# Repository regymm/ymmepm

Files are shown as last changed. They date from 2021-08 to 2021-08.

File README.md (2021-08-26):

## YMMEPM

#### CPLD Dev Board & Handheld Serial Terminal

Board with Altera MAX II EPM1270. With a pluggable 480x320 LCD screen and a matrix keyboard, it work well as a handheld serial terminal. [Video](https://t.me/petergulife/174). 

**Gallery**

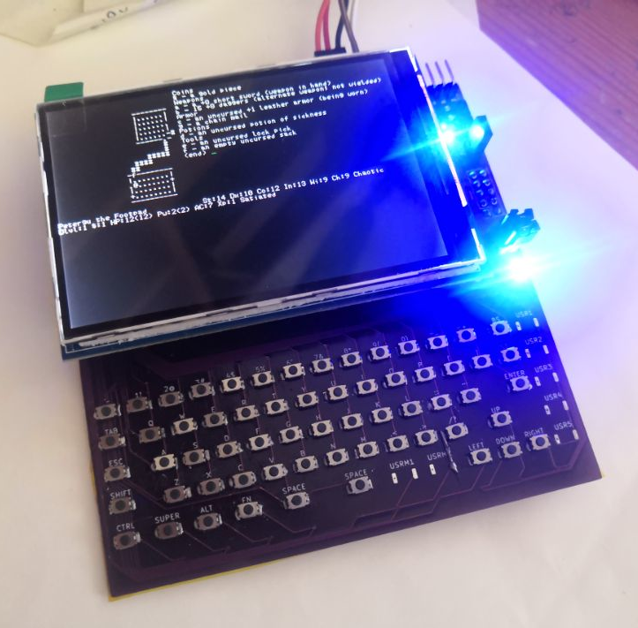
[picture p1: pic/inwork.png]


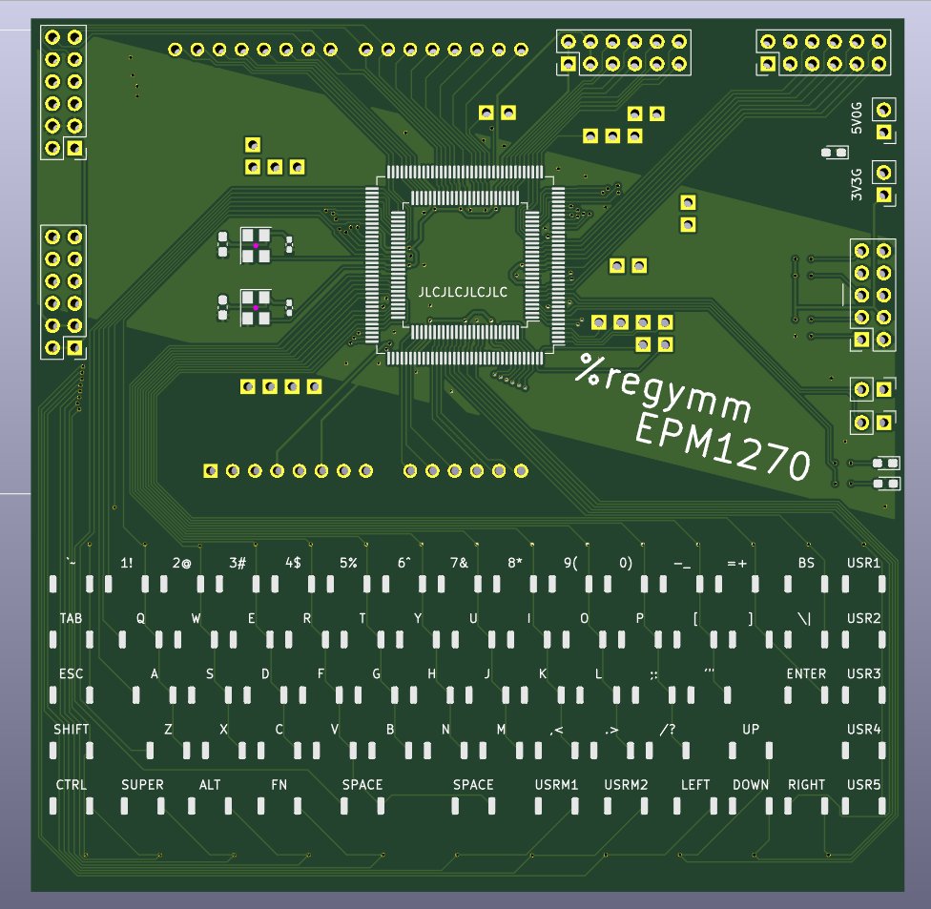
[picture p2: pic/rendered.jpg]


**The terminal**

`rtl/lcd_terminal.v`

Due to the scares resource of the EPM1270, the terminal supports only basic cursor movement and clear VT100(`^[[X`) sequences, others are detected and ignored. Have to put character pixel lists into slow UFM, so only up to 19200 baud rate. In case of Linux, bash and commands like `ls` work. `nano` won't display correctly and the editor that works is `ed` or my [ymedit](https://github.com/regymm/ymedit). CTS flow control is utilized to avoid losing chars when clearing full screen. (so need to connect 5 wires to use: 5V0, GND, rx, tx, cts)

**The keyboard**

`rtl/uart_keyboard.v`

Currently support only single-byte chars, arrow keys won't work. In code UP and RIGHT are used as extra SHIFT and CTRL. 

Covering keyboard with high-temperature yellow tape will significantly improve type feeling. 

**Design**

Simple is the main concern ... or not?

Single 3V3, or single 5V0 with ASM1117 to 3V3. 

Right two PMODs directly connected to CPLD. Left 2 PMODs share the Arduino pins(these literally give the plugged LCD screen a PMOD interface). Spare IOs scattered here and there. 

1 power LED, 2 user LEDs, 2 user jumpers. 2 oscillators. A strange matrix keyboard. 

For the simplest verification, only the CPLD, power pins, and JTAG pins are needed. Even caps on the back can be left empty. 

Footprint is compatible with EPM1270/570/240 TQFP144/100, but certainly the full terminal can only fit into EPM1270(~ 90% logic elements used). 

**Bugs**

5V is not connected to the Arduino pin. Fly a wire from ASM1117 if using 5V LCD screen. 

JTAG header pins should be soldered on back of the board. 

Still some tiny problems in the supported VT100 controls. But if the fix is paid in extra logic elements, I have to consider.

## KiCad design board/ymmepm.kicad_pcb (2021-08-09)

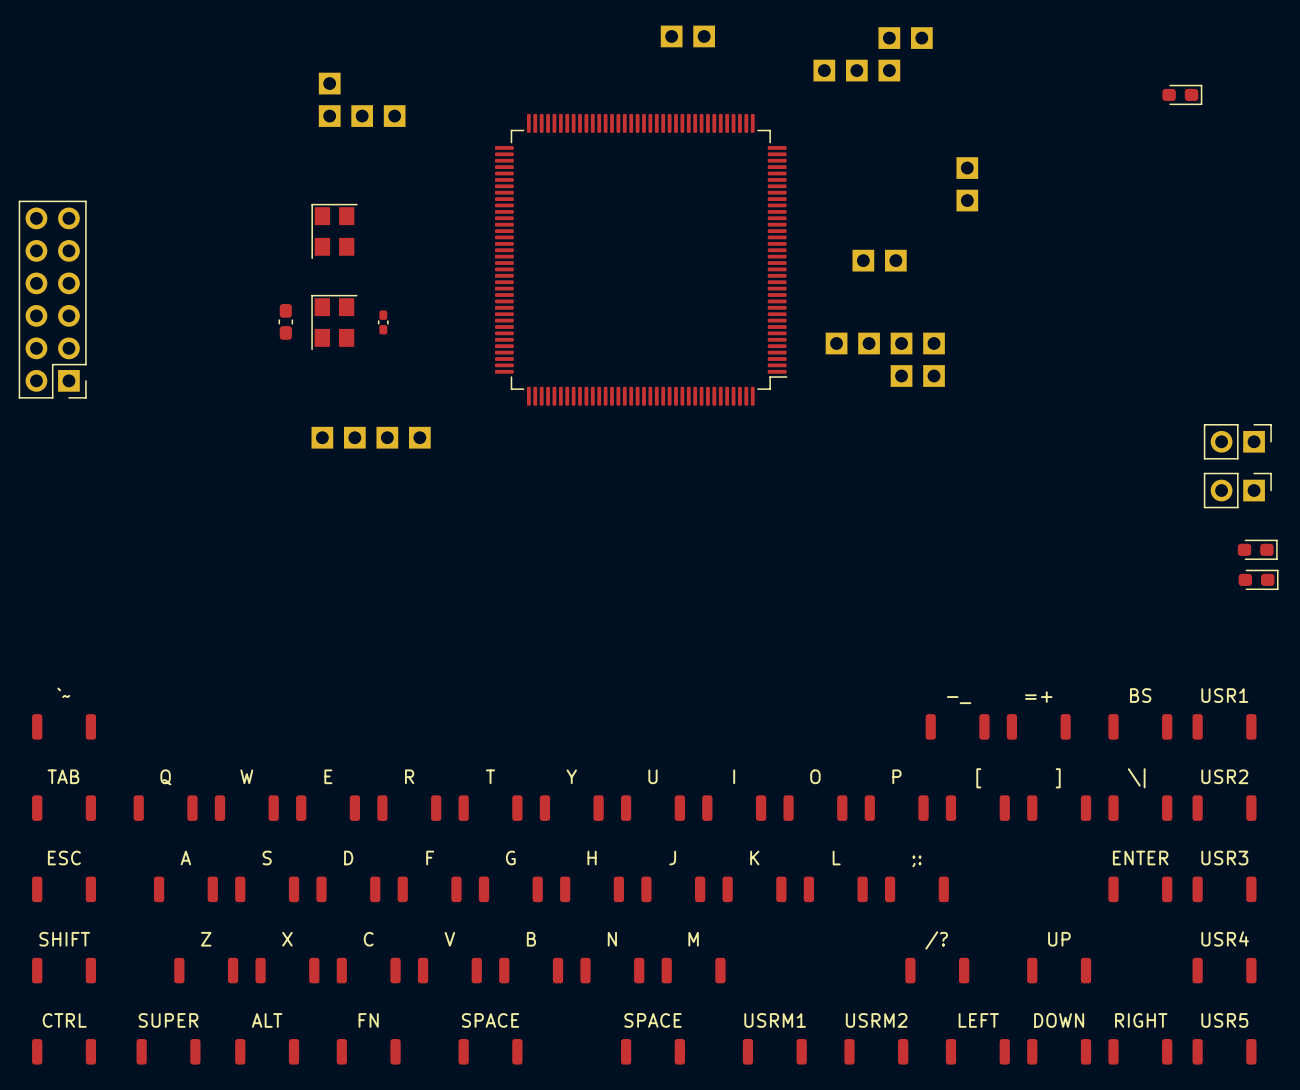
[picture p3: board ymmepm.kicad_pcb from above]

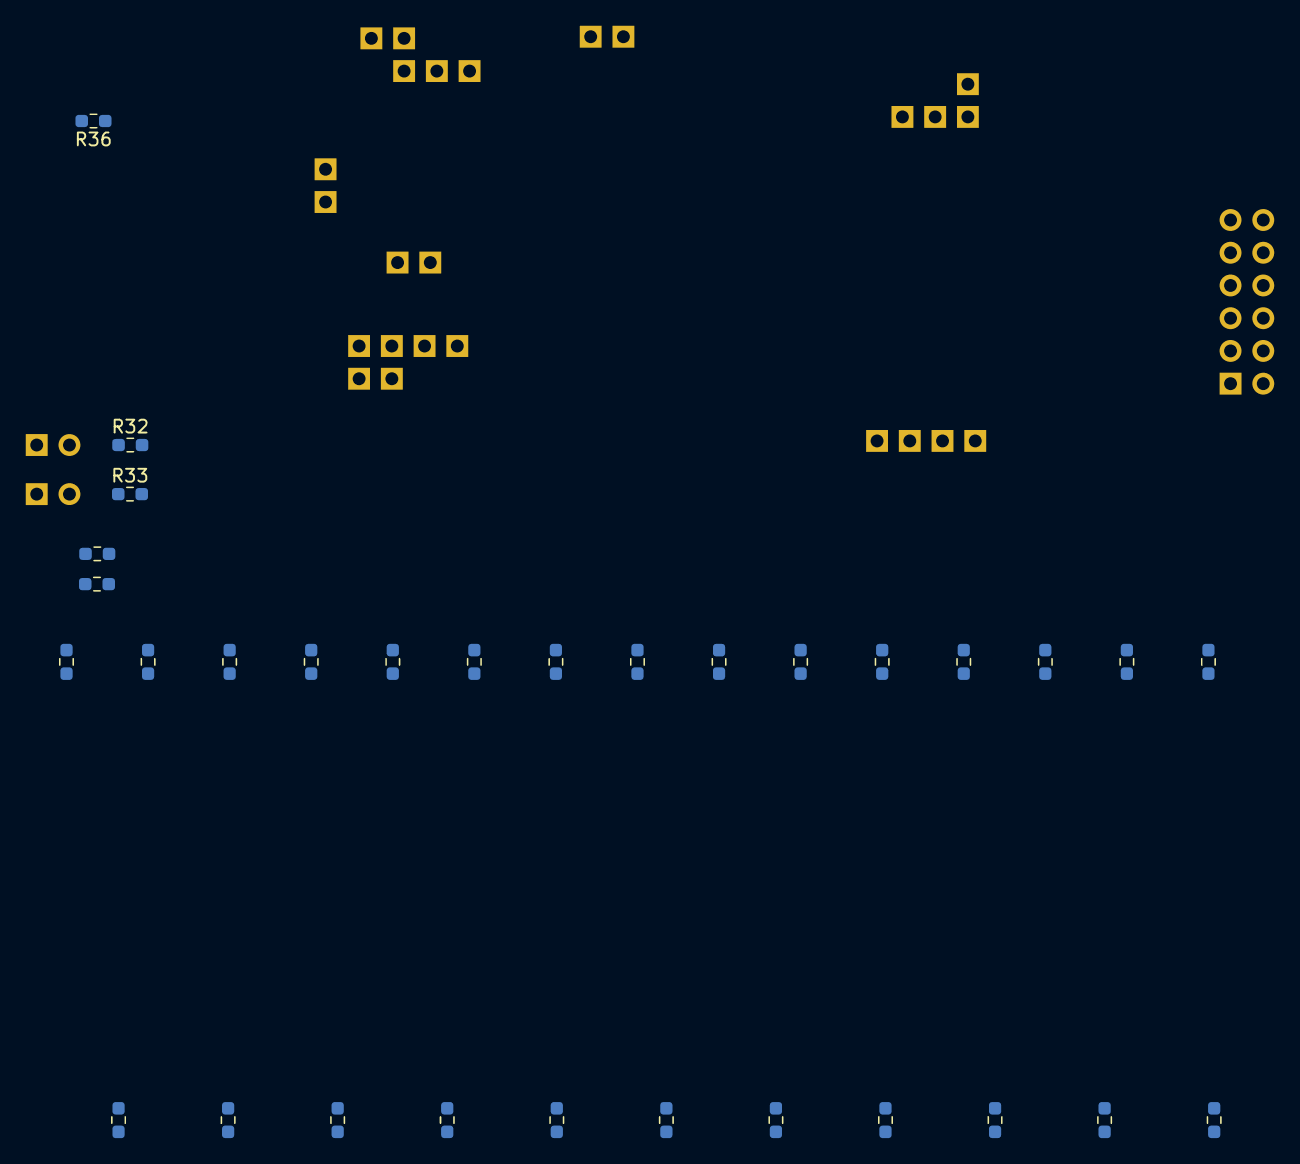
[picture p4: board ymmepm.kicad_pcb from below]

Board: 2 copper layers, 124 parts (31 on the bottom side), 76 nets, no tracks yet.

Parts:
'1: KEY; SW_Push_SPST_NO_Alps_SKRK_BARE
-1: KEY; SW_Push_SPST_NO_Alps_SKRK_BARE
/1: KEY; SW_Push_SPST_NO_Alps_SKRK_BARE
;1: KEY; SW_Push_SPST_NO_Alps_SKRK_BARE
=1: KEY; SW_Push_SPST_NO_Alps_SKRK_BARE
A1: KEY; SW_Push_SPST_NO_Alps_SKRK_BARE
AD1: KEY; SW_Push_SPST_NO_Alps_SKRK_BARE
AL1: KEY; SW_Push_SPST_NO_Alps_SKRK_BARE
ALT1: KEY; SW_Push_SPST_NO_Alps_SKRK_BARE
AR1: KEY; SW_Push_SPST_NO_Alps_SKRK_BARE
AU1: KEY; SW_Push_SPST_NO_Alps_SKRK_BARE
B1: KEY; SW_Push_SPST_NO_Alps_SKRK_BARE
BS1: KEY; SW_Push_SPST_NO_Alps_SKRK_BARE
C17: KEY; SW_Push_SPST_NO_Alps_SKRK_BARE
C18: C; C_0603_1608Metric_Pad1.08x0.95mm_HandSolder
C19: C0402; C_0402_1005Metric_Pad0.74x0.62mm_HandSolder
CTRL1: KEY; SW_Push_SPST_NO_Alps_SKRK_BARE
D1: KEY; SW_Push_SPST_NO_Alps_SKRK_BARE
D2, D3, D4: LED; LED_0603_1608Metric_Pad1.05x0.95mm_HandSolder
E1: KEY; SW_Push_SPST_NO_Alps_SKRK_BARE
ESC1: KEY; SW_Push_SPST_NO_Alps_SKRK_BARE
ETR1: KEY; SW_Push_SPST_NO_Alps_SKRK_BARE
F1: KEY; SW_Push_SPST_NO_Alps_SKRK_BARE
FN1: KEY; SW_Push_SPST_NO_Alps_SKRK_BARE
G1: KEY; SW_Push_SPST_NO_Alps_SKRK_BARE
H1: KEY; SW_Push_SPST_NO_Alps_SKRK_BARE
I1: KEY; SW_Push_SPST_NO_Alps_SKRK_BARE
J11: KEY; SW_Push_SPST_NO_Alps_SKRK_BARE
J13: JP1; PinHeader_1x02_P2.54mm_Vertical
J14: JP2; PinHeader_1x02_P2.54mm_Vertical
J15: PMOD1; PinHeader_2x06_P2.54mm_Vertical
J16, J17, J18, J19, J20, J21, J22, J23, J24, J25, J26, J27, J28, J29, J30, J31, J32, J33, J34, J35, J36, J37, J38, J39, J40: HOLE; PinHeader_1x01_P2.54mm_Vertical_BARE
K1: KEY; SW_Push_SPST_NO_Alps_SKRK_BARE
L1: KEY; SW_Push_SPST_NO_Alps_SKRK_BARE
M1: KEY; SW_Push_SPST_NO_Alps_SKRK_BARE
N1: KEY; SW_Push_SPST_NO_Alps_SKRK_BARE
O1: KEY; SW_Push_SPST_NO_Alps_SKRK_BARE
P1: KEY; SW_Push_SPST_NO_Alps_SKRK_BARE
Q1: KEY; SW_Push_SPST_NO_Alps_SKRK_BARE
R5: KEY; SW_Push_SPST_NO_Alps_SKRK_BARE
R6, R7, R8, R9, R10, R11, R12, R13, R14, R15, R16, R17, R18, R19, R20, R21, R22, R23, R24, R25, R26, R27, R28, R29, R30, R31, R32, R33, R34, R35, R36: R; R_0603_1608Metric_Pad0.98x0.95mm_HandSolder
S1: KEY; SW_Push_SPST_NO_Alps_SKRK_BARE
SHIFT1: KEY; SW_Push_SPST_NO_Alps_SKRK_BARE
SP1, SP2: KEY; SW_Push_SPST_NO_Alps_SKRK_BARE
SUPER1: KEY; SW_Push_SPST_NO_Alps_SKRK_BARE
T1: KEY; SW_Push_SPST_NO_Alps_SKRK_BARE
TAB1: KEY; SW_Push_SPST_NO_Alps_SKRK_BARE
U1: EPM1270T144; LQFP-144_20x20mm_P0.5mm
U3: KEY; SW_Push_SPST_NO_Alps_SKRK_BARE
USR1, USR2, USR3, USR4, USR5: KEY; SW_Push_SPST_NO_Alps_SKRK_BARE
USRM1, USRM2: KEY; SW_Push_SPST_NO_Alps_SKRK_BARE
V1: KEY; SW_Push_SPST_NO_Alps_SKRK_BARE
W1: KEY; SW_Push_SPST_NO_Alps_SKRK_BARE
X1, X3: Just an OSC; Oscillator_SMD_SeikoEpson_SG8002CE-4Pin_3.2x2.5mm
X2: KEY; SW_Push_SPST_NO_Alps_SKRK_BARE
Y1: KEY; SW_Push_SPST_NO_Alps_SKRK_BARE
Z1: KEY; SW_Push_SPST_NO_Alps_SKRK_BARE
[1: KEY; SW_Push_SPST_NO_Alps_SKRK_BARE
\1: KEY; SW_Push_SPST_NO_Alps_SKRK_BARE
]1: KEY; SW_Push_SPST_NO_Alps_SKRK_BARE
`1: KEY; SW_Push_SPST_NO_Alps_SKRK_BARE

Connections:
+3V3: C18.1, C19.1, J13.1, J14.1, J15.1, J15.2, R6.1, R7.1, R8.1, R9.1, R10.1, R11.1, R12.1, R13.1, R14.1, R15.1, R16.1, R17.1, R18.1, R19.1, R20.1, R21.1, R22.1, R23.1, R24.1, R25.1, R26.1, R27.1, R28.1, R29.1, R30.1, R31.1, R36.2, U1.9, U1.19, U1.25, U1.46, U1.56, U1.64, U1.82, U1.90, U1.100, U1.116, U1.126, U1.136, X1.4, X3.4
/IO1: J30.1, U1.1
/IO2: J29.1, U1.2
/IO3: J28.1, U1.3
/IO4: J23.1, U1.4
/IO5: CTRL1.2, R13.2, U1.5
/IO6: R11.2, SHIFT1.2, U1.6
/IO7: R35.2, U1.7
/IO8: R34.2, U1.8
/IO11: J14.2, R33.1, U1.11
/IO12: J13.2, R32.1, U1.12
/IO15: J21.1, U1.15
/IO16: J22.1, U1.16
/IO27: J27.1, U1.27
/IO28: J26.1, U1.28
/IO29: J25.1, U1.29
/IO30: J24.1, U1.30
/IO31: J20.1, U1.31
/IO32: J19.1, U1.32
/IO37: J18.1, U1.37
/IO48: J16.1, U1.48
/IO49: J17.1, U1.49
/IO73: SP1.1, SP2.1, U1.73, USR5.1
/IO74: /1.1, B1.1, C17.1, ESC1.1, M1.1, N1.1, U1.74, USR4.1, V1.1, X2.1, Z1.1
/IO75: ;1.1, A1.1, D1.1, ETR1.1, F1.1, G1.1, H1.1, J11.1, K1.1, L1.1, S1.1, TAB1.1, U1.75, USR3.1
/IO76: E1.1, I1.1, O1.1, P1.1, Q1.1, R5.1, T1.1, U1.76, U3.1, USR2.1, W1.1, Y1.1, [1.1, \1.1, ]1.1, `1.1
/IO77: -1.1, =1.1, BS1.1, U1.77, USR1.1
/IO78: J15.12, U1.78
/IO79: J15.11, U1.79
/IO80: J15.10, U1.80
/IO81: ESC1.2, R6.2, TAB1.2, U1.81, `1.2
/IO84: J37.1, U1.84
/IO85: J38.1, U1.85
/IO86: J39.1, U1.86
/IO87: J40.1, U1.87
/IO88: A1.2, Q1.2, R7.2, U1.88, Z1.2
/IO89: U1.89, X1.3
/IO91: U1.91, X3.3
/IO93: R8.2, S1.2, U1.93, W1.2, X2.2
/IO94: C17.2, D1.2, E1.2, R9.2, U1.94
/IO95: F1.2, R5.2, R10.2, SP1.2, SP2.2, U1.95, V1.2
/IO96: B1.2, G1.2, R12.2, T1.2, U1.96
/IO97: H1.2, N1.2, R14.2, U1.97, Y1.2
/IO98: J11.2, M1.2, R16.2, U1.98, U3.2
/IO101: I1.2, K1.2, R18.2, U1.101
/IO102: L1.2, O1.2, R20.2, U1.102
/IO103: /1.2, ;1.2, P1.2, R22.2, U1.103
/IO104: -1.2, R24.2, U1.104, [1.2
/IO105: =1.2, ETR1.2, R26.2, U1.105, ]1.2
/IO106: J33.1, U1.106
/IO107: J34.1, U1.107
/IO108: J35.1, U1.108
/IO109: J36.1, U1.109
/IO112: J15.6, U1.112
/IO113: J15.5, U1.113
/IO114: J15.8, U1.114
/IO119: J15.7, U1.119
/IO120: J15.9, U1.120
/IO122: BS1.2, R28.2, U1.122, \1.2
/IO123: R30.2, U1.123, USR1.2, USR2.2, USR3.2, USR4.2, USR5.2
/IO124: AD1.1, AL1.1, ALT1.1, AR1.1, AU1.1, CTRL1.1, FN1.1, SHIFT1.1, SUPER1.1, U1.124, USRM1.1, USRM2.1
/IO125: AR1.2, R27.2, U1.125
/IO127: AD1.2, R25.2, U1.127
/IO129: AU1.2, R23.2, U1.129
/IO137: AL1.2, R21.2, U1.137
/IO138: R31.2, U1.138, USRM2.2
/IO139: R29.2, U1.139, USRM1.2
/IO140: FN1.2, R19.2, U1.140
/IO141: ALT1.2, R17.2, U1.141
/IO142: R15.2, SUPER1.2, U1.142
/IO143: J31.1, U1.143
/IO144: J32.1, U1.144
GND: C18.2, C19.2, D2.1, D3.1, D4.1, J15.3, J15.4, R32.2, R33.2, U1.10, U1.17, U1.26, U1.47, U1.54, U1.65, U1.83, U1.92, U1.99, U1.115, U1.128, U1.135, X1.2, X3.2
unnamed: D2.2, R34.1
unnamed: D3.2, R35.1
unnamed: D4.2, R36.1

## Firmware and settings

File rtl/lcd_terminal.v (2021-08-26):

`timescale 1ns / 1ps

module lcd_terminal
(
	input clk,
	output [7:0]d,
	output rd,
	output wr,
	output rs,
	output cs,
	output rst,
	input rx,
	output rts
);
	assign rst = 1;
	assign rd = 1;
	assign rs = !(state == SEND_C);
	//assign cs = !(state == SEND_C | state == SEND_D);
	assign cs = 0;
	assign wr = !((state == SEND_C & cnt[0] == 0) | (state == SEND_D & cnt[0] == 0 & param_num != 0)); // 
	assign d = !rs ? command : param;

	reg [0:0]clk_reg = 0;
	always @ (posedge clk) begin
		clk_reg <= clk_reg + 1;
	end
	wire clk_en = (clk_reg[0] == 0);

	reg [22:0]cnt = 0;

	localparam RST = 0;
	localparam SLPOUT = 1;
	localparam DISPON = 2;
	localparam MAC = 3;
	localparam COLMOD = 4;
	localparam VOLT_1 = 5;
	localparam VOLT_2 = 6;
	localparam CLEAR_1 = 7;
	localparam CLEAR_2 = 8;
	localparam IDLE = 9;
	localparam CAS = 10;
	localparam PAS = 11;
	localparam SEND_C = 12;
	localparam SEND_D = 13;
	localparam WCHAR = 14;
	localparam CLR_LINE_1 = 15;
	localparam CLR_LINE_2 = 16;
	localparam DRAW_CURSOR = 17;
	localparam CLR_CURSOR = 18;
	localparam CURSOR_MEM = 19;
	localparam GAMMA_1 = 20;
	localparam GAMMA_2 = 21;
	localparam WCHAR_2 = 22;
	//localparam SCROLL = 22;
	reg [5:0]state = RST;
	reg [5:0]state_ret;
	reg [5:0]state_ret_stash;

	localparam SOFT_RESET = 8'h01;
	localparam SLEEP_OUT = 8'h11;
	localparam DISPLAY_ON = 8'h29;
	localparam MEM_ACCESS_CTRL = 8'h36;
	localparam IF_PIXEL_FMT = 8'h3A;
	localparam COLUMN_A_SET = 8'h2A;
	localparam PAGE_A_SET = 8'h2B;
	localparam MEM_WRITE = 8'h2C;
	//localparam VERTICAL_SCROLL = 8'h37;

	reg [7:0]command;
	reg [27:0]param_num;
	reg [7:0]param;

	// TODO: BUG: control character & charrol charrow, more than one/zero

	// 6x8 font terminal
	reg [6:0]charcol = 0;
	reg [5:0]charrow = 39; // begin from laaaast line

	wire [6:0]charcol_next = charcol == 79 ? 0 : (charcol + 1);
	wire [5:0]charrow_next = charcol == 79 ? (charrow == 39 ? 0 : charrow + 1) : charrow;
	wire clear_new_line = charcol == 79; // one position earlier, to avoid clear line clears the newly writen char
	//wire [15:0]scroll = 39 - charrow;
	// ^H
	wire [6:0]charcol_bs = charcol == 0 ? 0 : (charcol - 1);
	wire [5:0]charrow_bs = charrow;
	// ^M
	wire [6:0]charcol_cr = 0;
	wire [5:0]charrow_cr = charrow;
	// ^J
	wire [6:0]charcol_lf = charcol;
	wire [5:0]charrow_lf = charrow == 39 ? 0 : (charrow + 1);
	// ^I
	wire [6:0]charcol_ht = charcol > 76 ? 79 : {charcol[6:2]+5'b1, 2'b0}; // 4 tab
	wire [5:0]charrow_ht = charrow;
	// \033[A
	wire [5:0]charrow_up = charrow == 0 ? 0 : charrow - 1;

	//wire [5:0]charrow_below = charrow == 39 ? 0 : (charrow + 1);
	
	reg printable_char;
	wire [7:0]char = charrecv_r;
	wire [41:0]char_pixel = 
		char >= 8'h20 ? char_pixel_ufm :
		{char[7:4], 2'b10, char[3:0], 8'b10111110, 24'b0};
	wire curr_pixel = char_pixel[41-(cnt>>2)];

	wire [4:0]r = 5'b11111;
	wire [5:0]g = 6'b111111;
	wire [4:0]b = 5'b11111;

	reg [1:0]clearing = 0;
	reg clear_k = 0;
	reg d_cursor = 0; // drawing or cleaning cursor
	reg o_cursor = 0; // operation on cursor
	reg [15:0]cas_sc;
	reg [15:0]cas_ec;
	reg [15:0]pas_sp;
	reg [15:0]pas_ep;
	//wire [15:0]cas_sc = clearing != 0 ? 0 : charcol * 6;
	//wire [15:0]cas_ec = clearing != 0 ? 479 : charcol * 6 + 5;
	//wire [15:0]pas_sp = 
		//clearing == 1 ? 0  :
		//clearing == 2 ? charrow * 8 + 8 : charrow * 8 + o_cursor * 7;
	//wire [15:0]pas_ep =
		//clearing == 1 ? 319 : 
		//clearing == 2 ? charrow * 8 + 31 : charrow * 8 + 7;
	always @ (*) begin
		if (clearing == 1) begin
			if (clear_k) begin
				cas_sc = charcol * 6;
				cas_ec = 479;
				pas_sp = charrow * 8;
				pas_ep = charrow * 8 + 7;
			end else begin
				cas_sc = 0;
				cas_ec = 479;
				pas_sp = 0;
				pas_ep = 319;
			end
		end else if (clearing == 2) begin
			cas_sc = 0;
			cas_ec = 479;
			pas_sp = charrow * 8 + 8;
			pas_ep = charrow * 8 + 31;
		end else begin
			cas_sc = charcol * 6;
			cas_ec = charcol * 6 + 5;
			pas_sp = charrow * 8 + o_cursor * 7;
			pas_ep = charrow * 8 + 7;
		end
	end

	always @ (*) begin
		param = 8'h00;
		case (command)
			MEM_ACCESS_CTRL: param = 8'h28;
			IF_PIXEL_FMT: param = 8'h55;
			8'hC1: param = 8'h41;
			8'hC5: begin case (param_num)
				4: param = 8'h00;
				3: param = 8'h91;
				2: param = 8'h80;
				1: param = 8'h00;
			endcase end
			//8'hE0: begin case (param_num)
				//15: param = 8'h0F;
				//14: param = 8'h1F;
				//13: param = 8'h1C;
				//12: param = 8'h0C;
				//11: param = 8'h0F;
				//10: param = 8'h08;
				//9: param = 8'h48;
				//8: param = 8'h98;
				//7: param = 8'h37;
				//6: param = 8'h0A;
				//5: param = 8'h13;
				//4: param = 8'h04;
				//3: param = 8'h11;
				//2: param = 8'h0D;
				//1: param = 8'h00;
			//endcase end
			//8'hE1: begin case (param_num)
				//15: param = 8'h0F;
				//14: param = 8'h32;
				//13: param = 8'h2E;
				//12: param = 8'h0B;
				//11: param = 8'h0D;
				//10: param = 8'h05;
				//9: param = 8'h47;
				//8: param = 8'h75;
				//7: param = 8'h37;
				//6: param = 8'h06;
				//5: param = 8'h10;
				//4: param = 8'h03;
				//3: param = 8'h24;
				//2: param = 8'h20;
				//1: param = 8'h00;
			//endcase end
			COLUMN_A_SET: begin case (param_num)
				4: param = cas_sc[15:8];
				3: param = cas_sc[7:0];
				2: param = cas_ec[15:8];
				1: param = cas_ec[7:0];
			endcase end
			PAGE_A_SET: begin case (param_num)
				4: param = pas_sp[15:8];
				3: param = pas_sp[7:0];
				2: param = pas_ep[15:8];
				1: param = pas_ep[7:0];
			endcase end
			MEM_WRITE: begin
				param = clearing != 0 ? 8'h00 : 
					o_cursor ? (d_cursor&!cursorhide ? 8'h07 : 8'h00) :
					(curr_pixel ? 
					//8'hff
					cnt[0] == 0 ? {r, g[5:3]} : {g[2:0], b}
					: 8'h00);
			end
		endcase
	end

	reg [3:0]w_steps = 0;
	
	localparam DBG = 0;
	localparam N = DBG ? 1 : 800000;
	localparam CLEAR_W_COUNT = DBG ? 10 : 2*480*320;
	localparam CLEAR_K_COUNT = DBG ? 10 : 2*6*8*80; // overflow but doesn't matter
	localparam CLEAR_L_COUNT = DBG ? 5 : 2*6*8*80*3;
	localparam DRAW_C_COUNT = 2*6;

	wire hasrecv;
	wire [7:0]charrecv;
	reg [7:0]charrecv_r;
	reg nextchar = 0;

	// 0: normal
	// 1: ESC pressed
	// 2: [ pressed
	// ? or number dropped
	// return to 0 and execute consequence if a-zA-Z
	reg [1:0]escaped = 0;
	reg hasparam1;
	reg hasparam2;
	reg [7:0]csi_param1;
	reg [7:0]csi_param2;
	wire [7:0]param1 = hasparam1 ? csi_param1 : 1;
	wire [7:0]param2 = hasparam2 ? csi_param2 : 1;
	reg param_1or2;
	reg cursorhide = 0;
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

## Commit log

2021-08-06 Start working on epm board
    [ymmepm.kicad_pcb, ymmepm.sch]
2021-08-08 Near close I think
    [ymmepm.kicad_pcb, ymmepm.sch]
2021-08-09 Go production at JLC purple
    [ymmepm-B_Cu.gbr, ymmepm-B_Mask.gbr, ymmepm-B_Paste.gbr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]
2021-08-14 Added some design files
    [ymmepm-B_Cu.gbr, ymmepm-B_Mask.gbr, ymmepm-B_Paste.gbr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]
